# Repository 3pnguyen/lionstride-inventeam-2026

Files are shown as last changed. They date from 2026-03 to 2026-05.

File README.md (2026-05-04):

# lionstride-inventeam-2026

## Branch for the schematic files of the circuit and device

 <!-- - --> 

<!-- Badeges from https://gprm.itsvg.in and https://github.com/Ileriayo/markdown-badges  -->

<div align="center">
    <table>
        <tr>
            <td></td>
            <td></td>
        </tr>
    </table>
</div>

## Images

| Prototype | Finalized |
| :---: | :---: |
| [Prototype VD (17.1)](Prototype%20Schematics/Prototype%20Schematic%20(VD)/Schematic%20Versions/Schematic%20V17/v17.1%20-%203.19.26/) | [Logic Schematic (V3)](Finalized%20Schematics/Finalized%20Logic%20Schematic/Schematic%20Versions/Schematic%20V03/) |
| Prototype TIA | [Thermistor Schematic (V2)](Finalized%20Schematics/Finalized%20Thermistor%20Schematic/Schematic%20Versions/Schematic%20V02/) | 
| | [Pressure Schematic (V2.2)](Finalized%20Schematics/Finalized%20Pressure%20Schematic/Schematic%20Versions/Schematic%20V02/V2.2%20-%205.3.2026/) |

<!-- %20 is used as a space -->

## Purpose

This branch holds all of the KiCad files of our schematics and electrical designs. Our prototype schematic holds everything, and is the main design that has gone through the most change. As we transition from a prototype build to a finished product, parts of our prototype become "finalized." Finalized schematics seperate into their own folder with their own changelogs and PCB design. Even those schematics undergo some significant change indicated by their version number.

## Changelogs

| Prototype | Finalized |
| :---: | :---: |
| [Prototype VD](Prototype%20Schematics/Prototype%20Schematic%20(VD)/changelog.md) | [Logic Schematic](Finalized%20Schematics/Finalized%20Logic%20Schematic/changelog.md) |
| Prototype TIA | [Thermistor Schematic](Finalized%20Schematics/Finalized%20Thermistor%20Schematic/changelog.md) | 
| | [Pressure Schematic](Finalized%20Schematics/Finalized%20Pressure%20Schematic/changelog.md) |

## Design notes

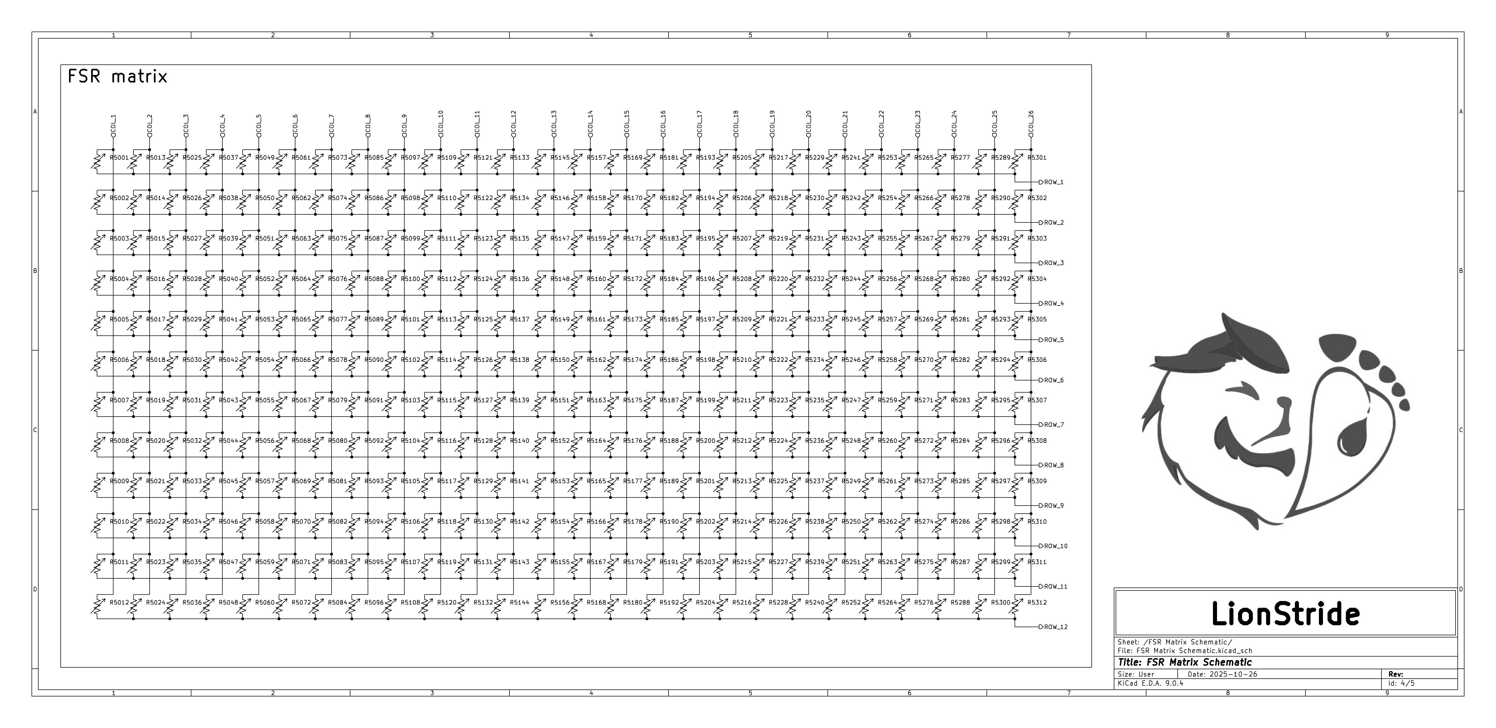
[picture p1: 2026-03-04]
Prototype Schematics/Prototype Schematic (VD)/Schematic Versions/Schematic V17/v17.1 - 3.19.26/FSR Matrix.png

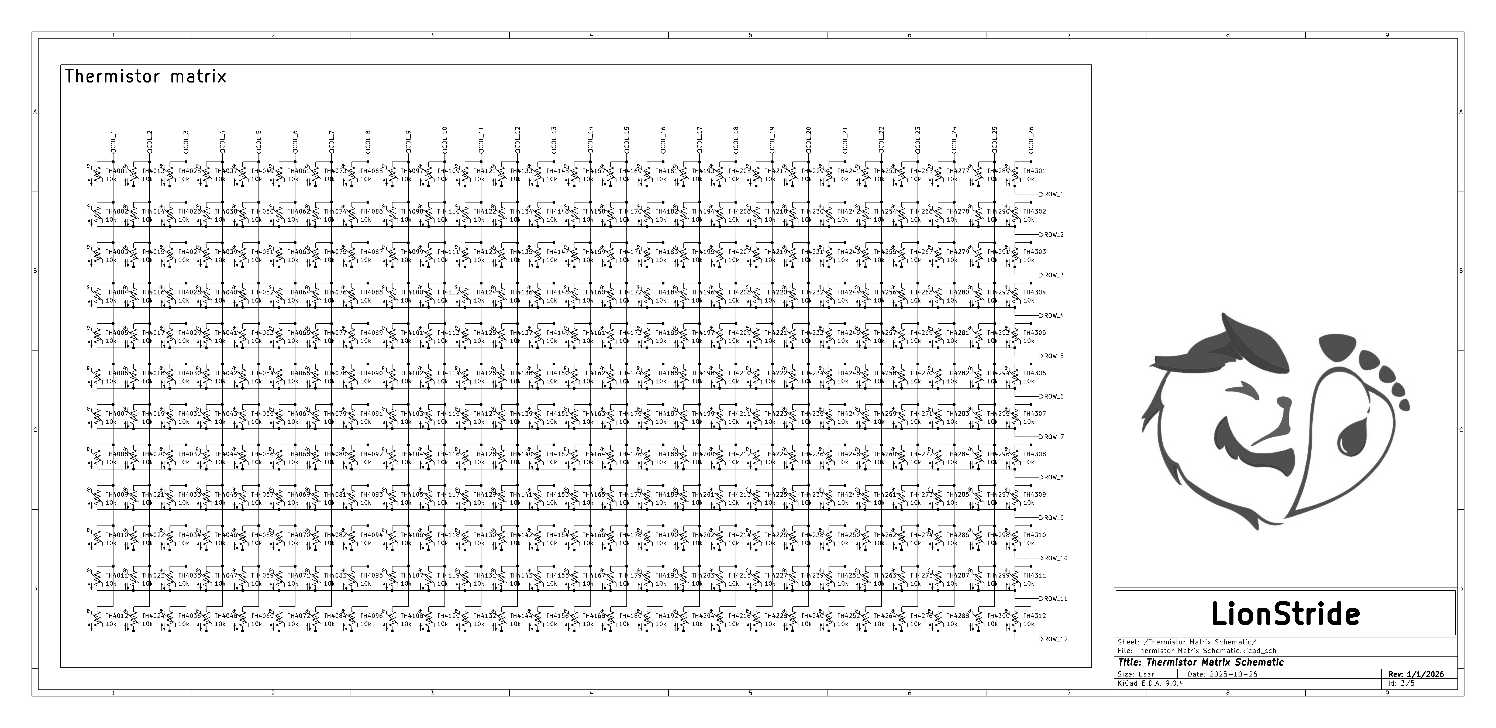
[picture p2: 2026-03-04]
Prototype Schematics/Prototype Schematic (VD)/Schematic Versions/Schematic V17/Thermistor Matrix.png

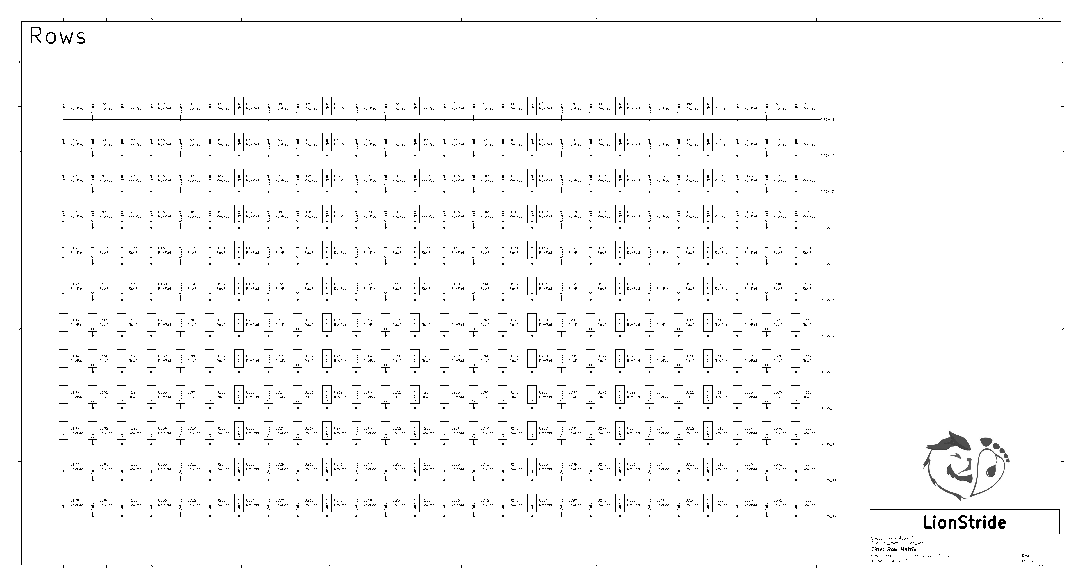
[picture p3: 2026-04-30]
Finalized Schematics/Finalized Pressure Schematic/Schematic Versions/Schematic V02/Rows Hierarchical Schematic.png

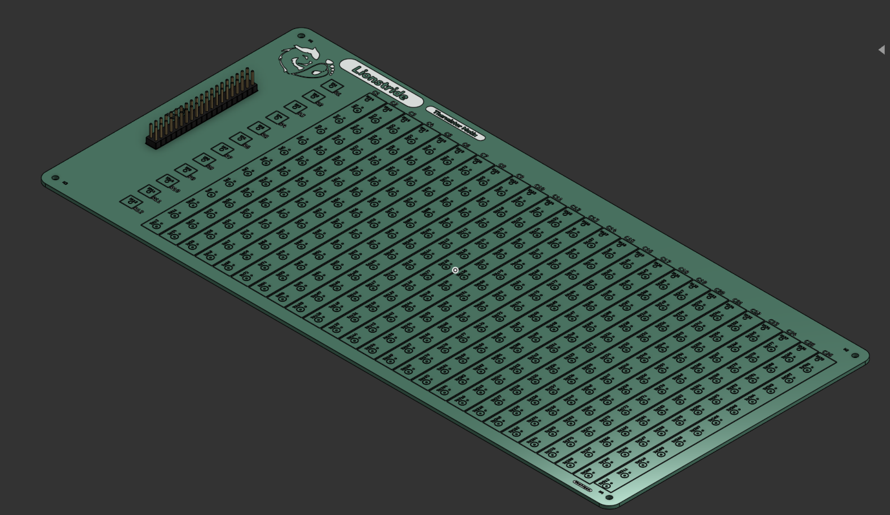
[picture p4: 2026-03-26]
Finalized Schematics/Finalized Thermistor Schematic/Schematic Versions/Schematic V02/Matrix Onshape.png

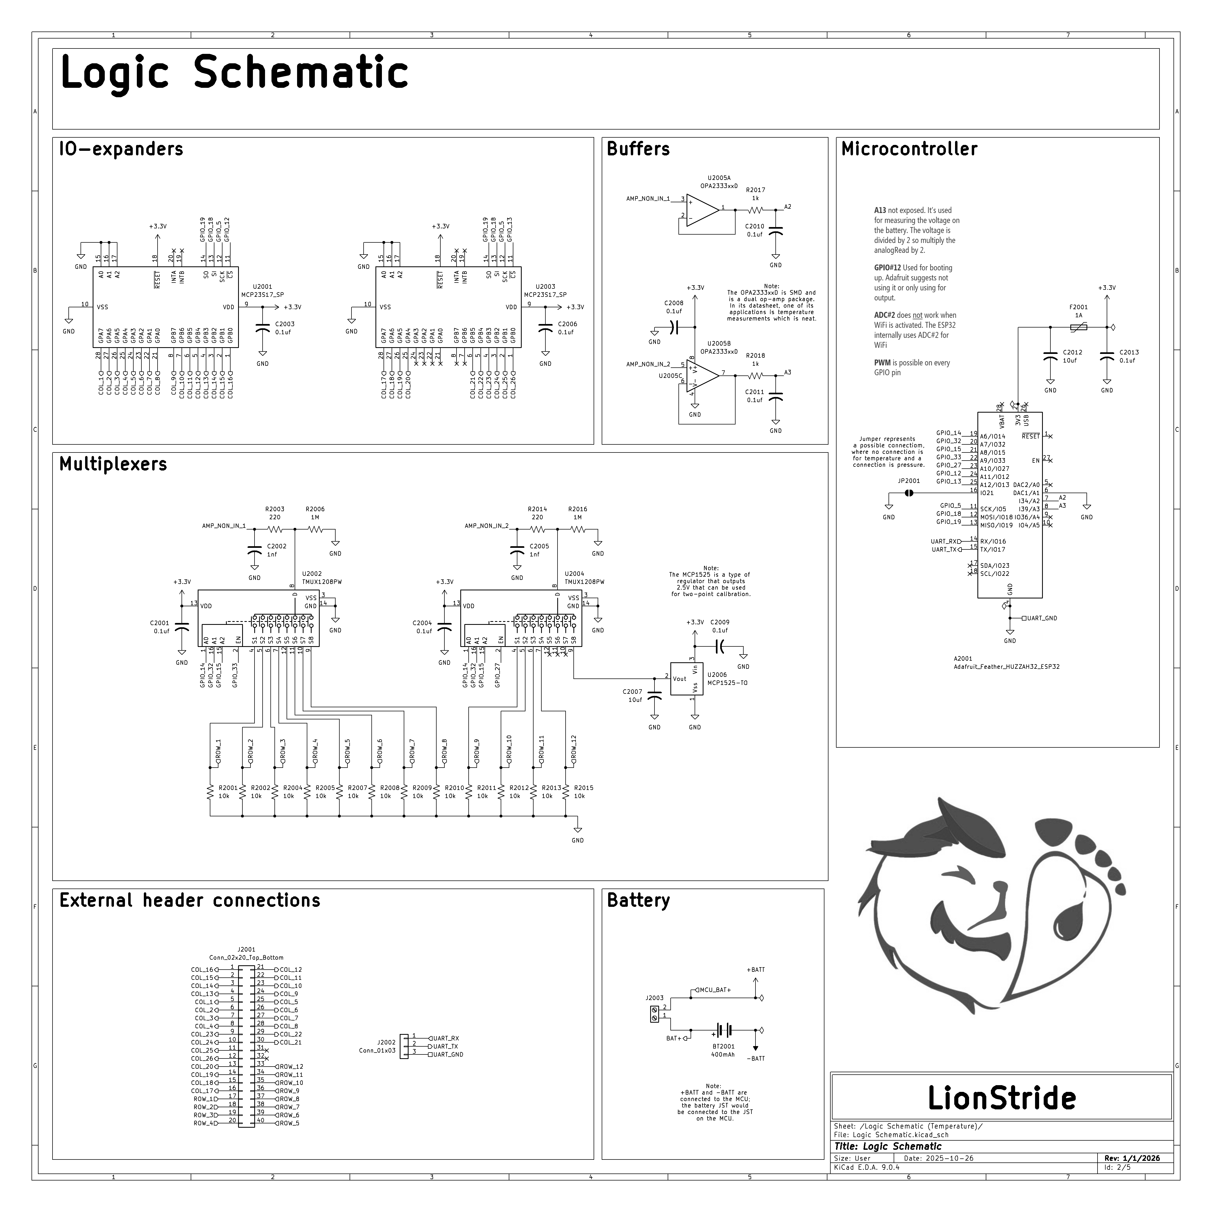
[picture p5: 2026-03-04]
Prototype Schematics/Prototype Schematic (VD)/Schematic Versions/Schematic V17/Logic Schematic.png

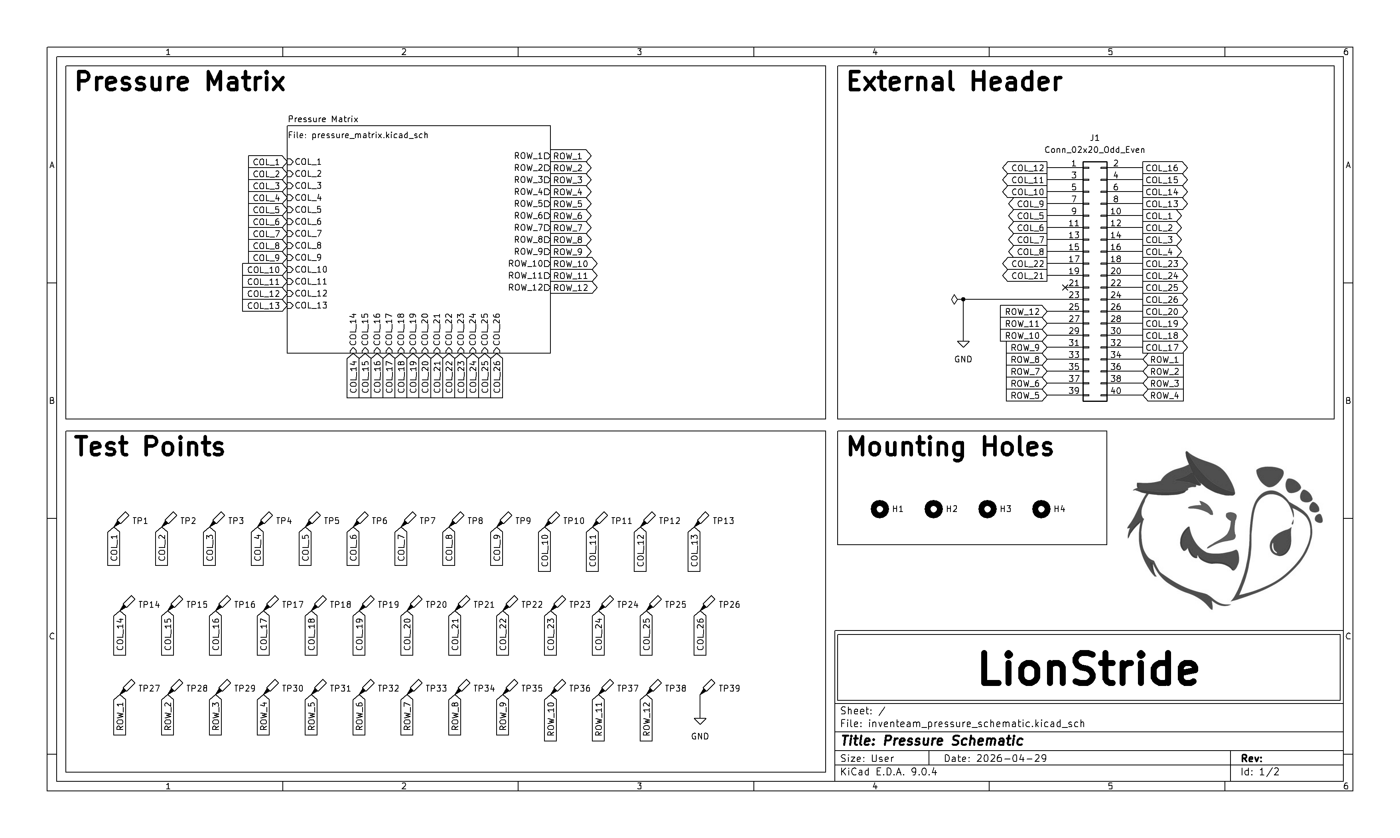
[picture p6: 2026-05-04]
Finalized Schematics/Finalized Pressure Schematic/Schematic Versions/Schematic V02/V2.2 - 5.3.2026/Pressure Schematic.png

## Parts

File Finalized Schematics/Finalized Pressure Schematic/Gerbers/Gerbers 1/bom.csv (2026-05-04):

Designator | Footprint | Quantity | Value | LCSC Part #
J1 | PinHeader_2x20_P2.54mm_Vertical | 1 | Conn_02x20_Odd_Even
TP1, TP10, TP11, TP12, TP13, TP14, TP15, TP16, TP17, TP18, TP19, TP2, TP20, TP21, TP22, TP23, TP24, TP25, TP26, TP27, TP28, TP29, TP3, TP30, TP31, TP32, TP33, TP34, TP35, TP36, TP37, TP38, TP39, TP4, TP5, TP6, TP7, TP8, TP9 | TestPoint_Pad_D2.5mm | 39 | TestPoint_Probe

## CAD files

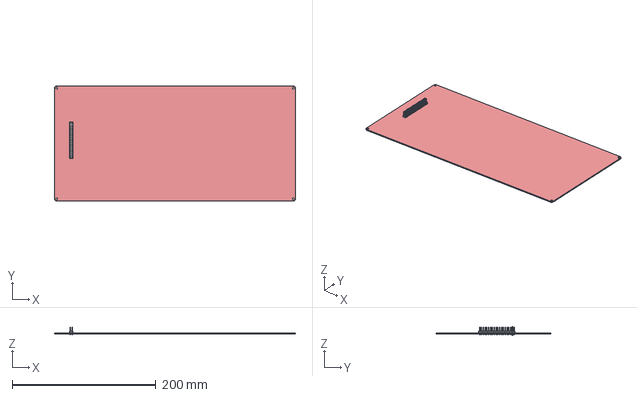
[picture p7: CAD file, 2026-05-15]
Finalized Schematics/Finalized Pressure Schematic/Gerbers/Gerbers 1/inventeam_pressure_schematic.step
335.0 x 160.0 x 11.5 mm
PinHeader_2x20_P2.54mm_Vertical
inventeam_pressure_schematic_PCB

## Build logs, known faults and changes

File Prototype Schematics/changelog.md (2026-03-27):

# Prototype design changelog:

(Version descriptions have been added since V16.1, so older version descriptions may be inaccurate.)

* V1 - 10.25.25: Original, early concept of the matrix design w/ the hardware to drive it
* V2 - 10.26.25: KiCad representation of V1
* V3 - 10.26.25: Concept for bigger matrix
* V4 - 10.26.25:  V2 refined with filtering and battery power
* V5 - 10.27.25: V4 but doubled matrix for two feet design
* V6 - 11.5.25: Revert back to one matrix and increase matrix size with more hardware
* V7 - 11.5.25: Revisions of V6 with better and more hardware
* V8 - 11.6.25: KiCad representation of V7
* V9 - 11.12.25: Separated V8 setup into hierarchical sheets for modular setup
* V10 - 11.14.25: Moved matrix into hierarchical sheet + more revisions
* V11 - 11.20.25: Refined hierarchical schematics more
* V12 - 11.27.25: More refinement w/ filtering on the ADCs
* V13 - 12.1.25: Added more decoupling and added more protection w/ polyfuses
	* V13.1 - 12.7.25: Added operational-amplifiers as voltage followers
	* V13.2 - 12.26.25: Added reference IC
* V14 - 1.1.26: Combine row and column hierarchical schematics together
	* V14.1 - 1.2.26: Switched row and column terminals to headers
	* V14.2 - 1.9.26: Combine row and column headers into one
	* V14.3 - 1.10.26: Removed external LED in favor of code
* V15 - 1.25.26: Added back the second matrix for pressure, created a logic schematic for pressure too
	* V15.1 - 2.13.26: Change decoupler on ref. IC output from 1uf to 10uf (no recording because I forgot)
	* V15.2 - 2.19.26: Added missing row 12 on the main header
* V16 - 2.22.26: Added RC filters and pull-down resistors between MUX drain pins and OP AMP non-inverting inputs
	* V16.1 - 3.2.26: Fixed reference designator conflicts and updated file names
* V17 - 3.3.26: Made universal version of logic schematic and moved reference IC to spare MUX pin
	* V17.1 - 3.19.26 - grounded one of the pins on the header

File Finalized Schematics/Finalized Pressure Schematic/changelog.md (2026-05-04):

# Finalized Pressure Schematic changelog:

* V1 - 4.11.26: Initialized first version of the pressure schematic 
* V2 - 4.29.26: Redesgined pressure schematic following changes of design
    * V2.1 - Modified V2 by adding test points and removing cell footprints in favor of one large one
    * V2.2 - Added GND test point, flipped the connections on the header

# Gerber files:
* Gerbers 1 (Schematic V2.2) - 5.3.2026: Created PCB design for schematic V2.2

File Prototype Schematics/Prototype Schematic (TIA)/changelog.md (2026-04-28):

# Prototype (TIA) design changelog:

* V0 - 4.27.26: Duplicated VD prototype (V17.1) to prepare for modifications on the newer prototype

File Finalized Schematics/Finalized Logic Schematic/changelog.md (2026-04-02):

# Finalized Logic Schematic chengelog:

* V1 - 3.18.26: Initialized and finished the initial PCB design schematic for the Logic schematic. (Two of the prototype Logic schematic + little extra)
	* V1.1 - 3.18.26: Optimize battery connections
	* V1.2 - 3.19.26: Add ground connections per header for thermistor matrix PCB
	* V1.3 - 3.27.26: Change header type on schematic, change 2A PPTC to 1A, added extra 0.1uf decoupler to USB C output, and finished assigning footprints
	* V1.4 - 3.28.26: Add 1x02 male header to make powering circuit more flexible + added missing decoupling for LM66100 ICs
* V2 - 3.31.2026: Made several optimizations and improvements including: Reording decouplers relative to IC(s), reording PPTC + TVS + decouplers relative to MCUs/sources, removing extra test points, moving the ADC RC filter next to the ADC for better filtering, and using hierarchal sheets again for the matrices logic
* V3 - 4.1.2026: Simplified schematic by removing USB C circuit, one ESP, and battery circuit. One ESP will be designated to drive two matrices

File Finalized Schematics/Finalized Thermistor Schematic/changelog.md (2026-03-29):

# Finalized Thermistor Matrix changelog:

* V1 - 3.20.26: Initialize schematic w/ additional header and mounting holes
* V2 - 3.25.26: Used hierarchal sheets to make PCB design easier (and made a PCB)

# Gerber files:

* Gerbers 1 (Schematic V2) - 3.25.26: Created PCB design for schematic V2
* Gerbers 2 (Schematic V2) - 3.29.26: Fixed problem where some of the PCB wasn't grounded w/ vias

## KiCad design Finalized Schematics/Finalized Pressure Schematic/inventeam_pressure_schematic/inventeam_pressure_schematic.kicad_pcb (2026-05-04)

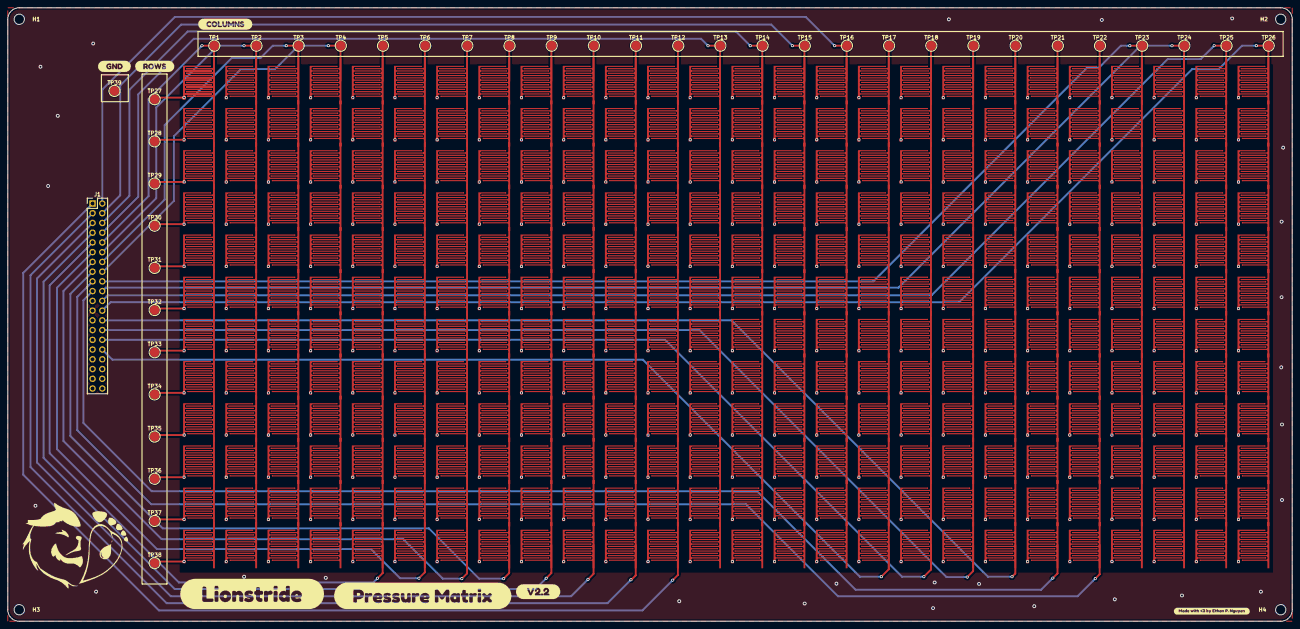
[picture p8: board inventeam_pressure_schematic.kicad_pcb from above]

Board: 4 copper layers, 335.0 x 160.0 mm, 51 parts (0 on the bottom side), 39 nets.

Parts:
H1, H2, H3, H4: MountingHole; MountingHole_2.7mm_M2.5
J1: Conn_02x20_Odd_Even; PinHeader_2x20_P2.54mm_Vertical
TP1, TP2, TP3, TP4, TP5, TP6, TP7, TP8, TP9, TP10, TP11, TP12, TP13, TP14, TP15, TP16, TP17, TP18, TP19, TP20, TP21, TP22, TP23, TP24, TP25, TP26, TP27, TP28, TP29, TP30, TP31, TP32, TP33, TP34, TP35, TP36, TP37, TP38, TP39: TestPoint_Probe; TestPoint_Pad_D2.5mm
kibuzzard-69F7F9B9: G***; kibuzzard-69F7F9B9
kibuzzard-69F7FA32: G***; kibuzzard-69F7FA32
kibuzzard-69F7FCC3: G***; kibuzzard-69F7FCC3
kibuzzard-69F7FCD4: G***; kibuzzard-69F7FCD4
kibuzzard-69F7FD79: G***; kibuzzard-69F7FD79
kibuzzard-69F8111F: G***; kibuzzard-69F8111F
kibuzzard-69F81189: G***; kibuzzard-69F81189

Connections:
COL_1: J1.10, TP1.1
COL_2: J1.12, TP2.1
COL_3: J1.14, TP3.1
COL_4: J1.16, TP4.1
COL_5: J1.9, TP5.1
COL_6: J1.11, TP6.1
COL_7: J1.13, TP7.1
COL_8: J1.15, TP8.1
COL_9: J1.7, TP9.1
COL_10: J1.5, TP10.1
COL_11: J1.3, TP11.1
COL_12: J1.1, TP12.1
COL_13: J1.8, TP13.1
COL_14: J1.6, TP14.1
COL_15: J1.4, TP15.1
COL_16: J1.2, TP16.1
COL_17: J1.32, TP17.1
COL_18: J1.30, TP18.1
COL_19: J1.28, TP19.1
COL_20: J1.26, TP20.1
COL_21: J1.19, TP21.1
COL_22: J1.17, TP22.1
COL_23: J1.18, TP23.1
COL_24: J1.20, TP24.1
COL_25: J1.22, TP25.1
COL_26: J1.24, TP26.1
GND: J1.23, TP39.1
ROW_1: J1.34, TP27.1
ROW_2: J1.36, TP28.1
ROW_3: J1.38, TP29.1
ROW_4: J1.40, TP30.1
ROW_5: J1.39, TP31.1
ROW_6: J1.37, TP32.1
ROW_7: J1.35, TP33.1
ROW_8: J1.33, TP34.1
ROW_9: J1.31, TP35.1
ROW_10: J1.29, TP36.1
ROW_11: J1.27, TP37.1
ROW_12: J1.25, TP38.1

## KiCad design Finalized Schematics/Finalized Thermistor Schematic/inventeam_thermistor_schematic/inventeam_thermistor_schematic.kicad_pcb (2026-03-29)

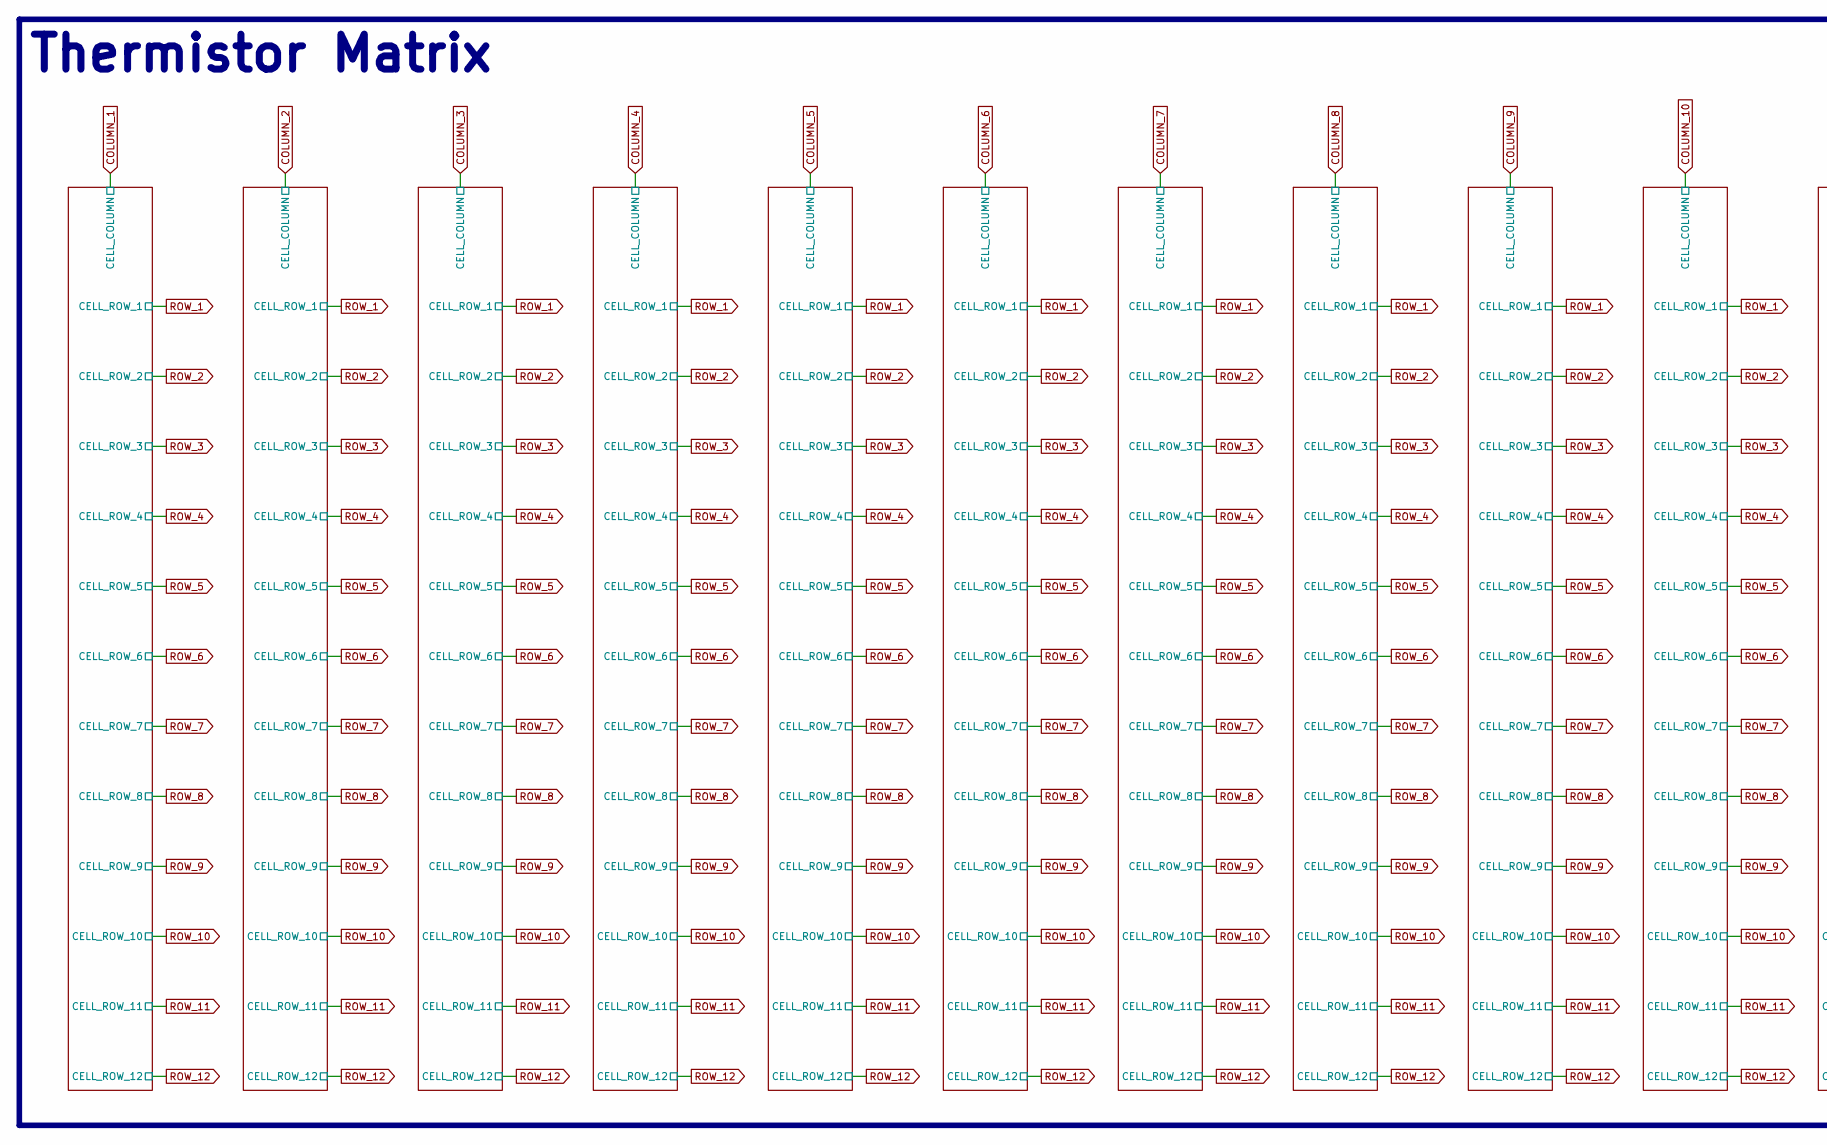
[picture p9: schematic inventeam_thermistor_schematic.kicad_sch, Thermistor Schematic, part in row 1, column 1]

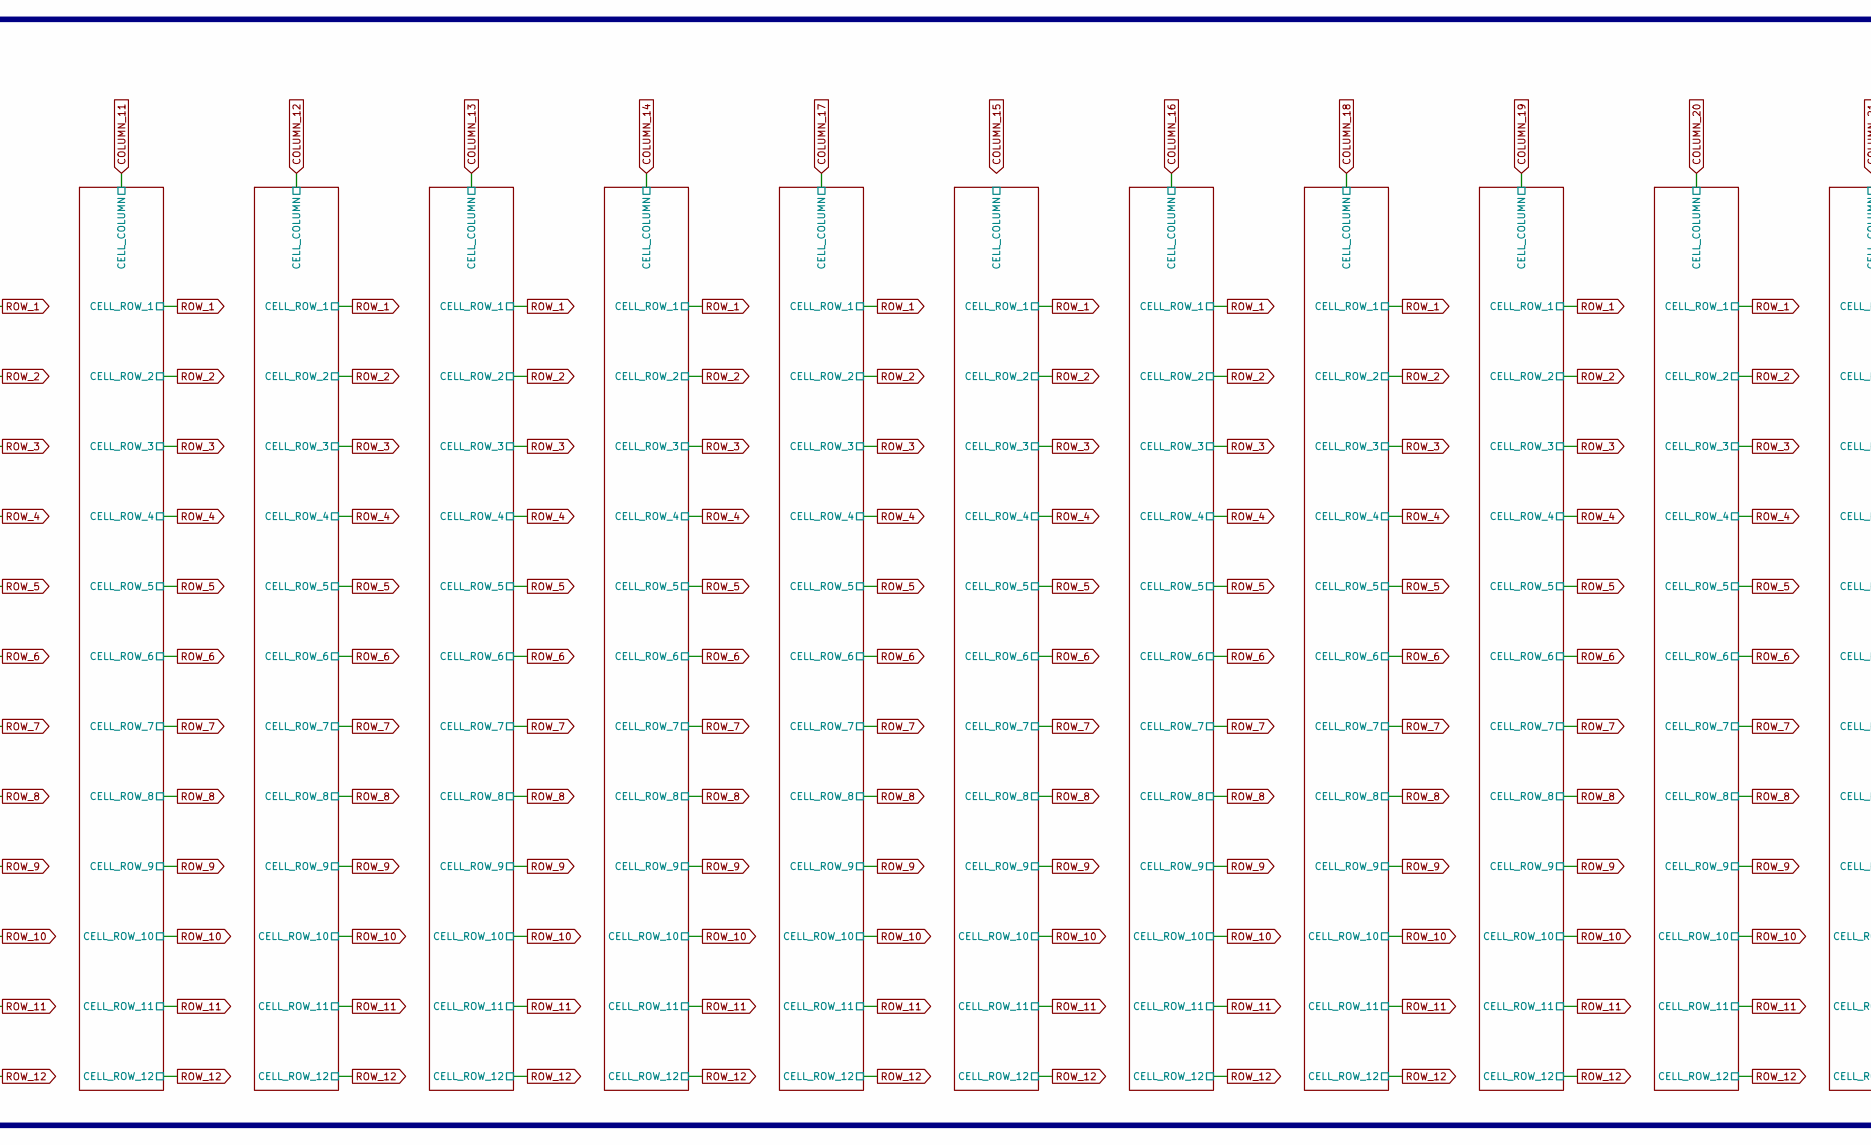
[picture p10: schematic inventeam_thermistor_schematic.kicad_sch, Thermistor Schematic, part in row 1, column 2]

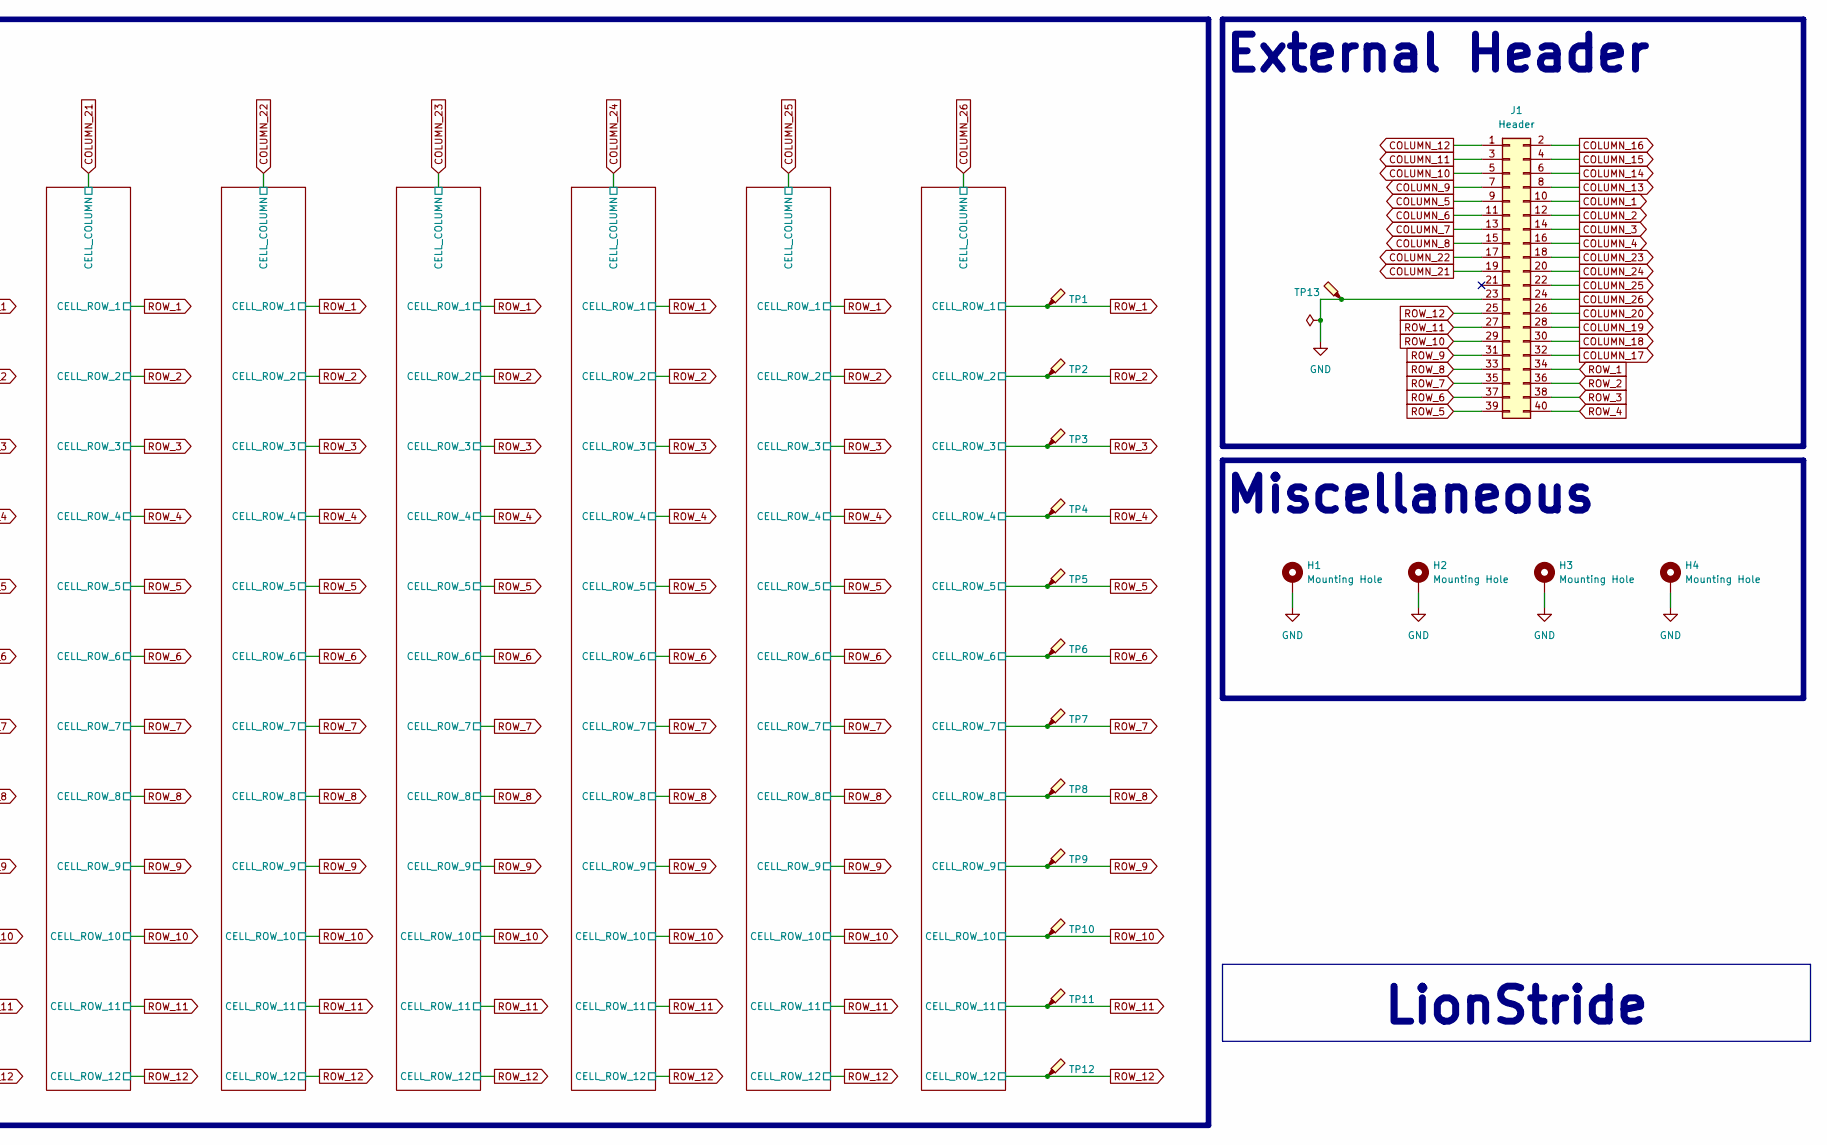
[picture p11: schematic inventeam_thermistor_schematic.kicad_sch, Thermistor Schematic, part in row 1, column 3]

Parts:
H1, H2, H3, H4: Mounting Hole; MountingHole_2.5mm_Pad
J1: Header; PinHeader_2x20_P2.54mm_Vertical
TP1, TP2, TP3, TP4, TP5, TP6, TP7, TP8, TP9, TP10, TP11, TP12, TP13: TestPoint_Probe; TestPoint_Pad_D1.0mm

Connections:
COLUMN_1: J1.10; also elsewhere on the board
COLUMN_2: J1.12; also elsewhere on the board
COLUMN_3: J1.14; also elsewhere on the board
COLUMN_4: J1.16; also elsewhere on the board
COLUMN_5: J1.9; also elsewhere on the board
COLUMN_6: J1.11; also elsewhere on the board
COLUMN_7: J1.13; also elsewhere on the board
COLUMN_8: J1.15; also elsewhere on the board
COLUMN_9: J1.7; also elsewhere on the board
COLUMN_10: J1.5; also elsewhere on the board
COLUMN_11: J1.3; also elsewhere on the board
COLUMN_12: J1.1; also elsewhere on the board
COLUMN_13: J1.8; also elsewhere on the board
COLUMN_14: J1.6; also elsewhere on the board
COLUMN_15: J1.4; also elsewhere on the board
COLUMN_16: J1.2; also elsewhere on the board
COLUMN_17: J1.32; also elsewhere on the board
COLUMN_18: J1.30; also elsewhere on the board
COLUMN_19: J1.28; also elsewhere on the board
COLUMN_20: J1.26; also elsewhere on the board
COLUMN_21: J1.19; also elsewhere on the board
COLUMN_22: J1.17; also elsewhere on the board
COLUMN_23: J1.18; also elsewhere on the board
COLUMN_24: J1.20; also elsewhere on the board
COLUMN_25: J1.22; also elsewhere on the board
COLUMN_26: J1.24; also elsewhere on the board
GND: H1.1, H2.1, H3.1, H4.1, J1.23, TP13.1
ROW_1: J1.34, TP1.1; also elsewhere on the board
ROW_2: J1.36, TP2.1; also elsewhere on the board
ROW_3: J1.38, TP3.1; also elsewhere on the board
ROW_4: J1.40, TP4.1; also elsewhere on the board
ROW_5: J1.39, TP5.1; also elsewhere on the board
ROW_6: J1.37, TP6.1; also elsewhere on the board
ROW_7: J1.35, TP7.1; also elsewhere on the board
ROW_8: J1.33, TP8.1; also elsewhere on the board
ROW_9: J1.31, TP9.1; also elsewhere on the board
ROW_10: J1.29, TP10.1; also elsewhere on the board
ROW_11: J1.27, TP11.1; also elsewhere on the board
ROW_12: J1.25, TP12.1; also elsewhere on the board

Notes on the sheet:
LionStride
Miscellaneous
External Header
Thermistor Matrix

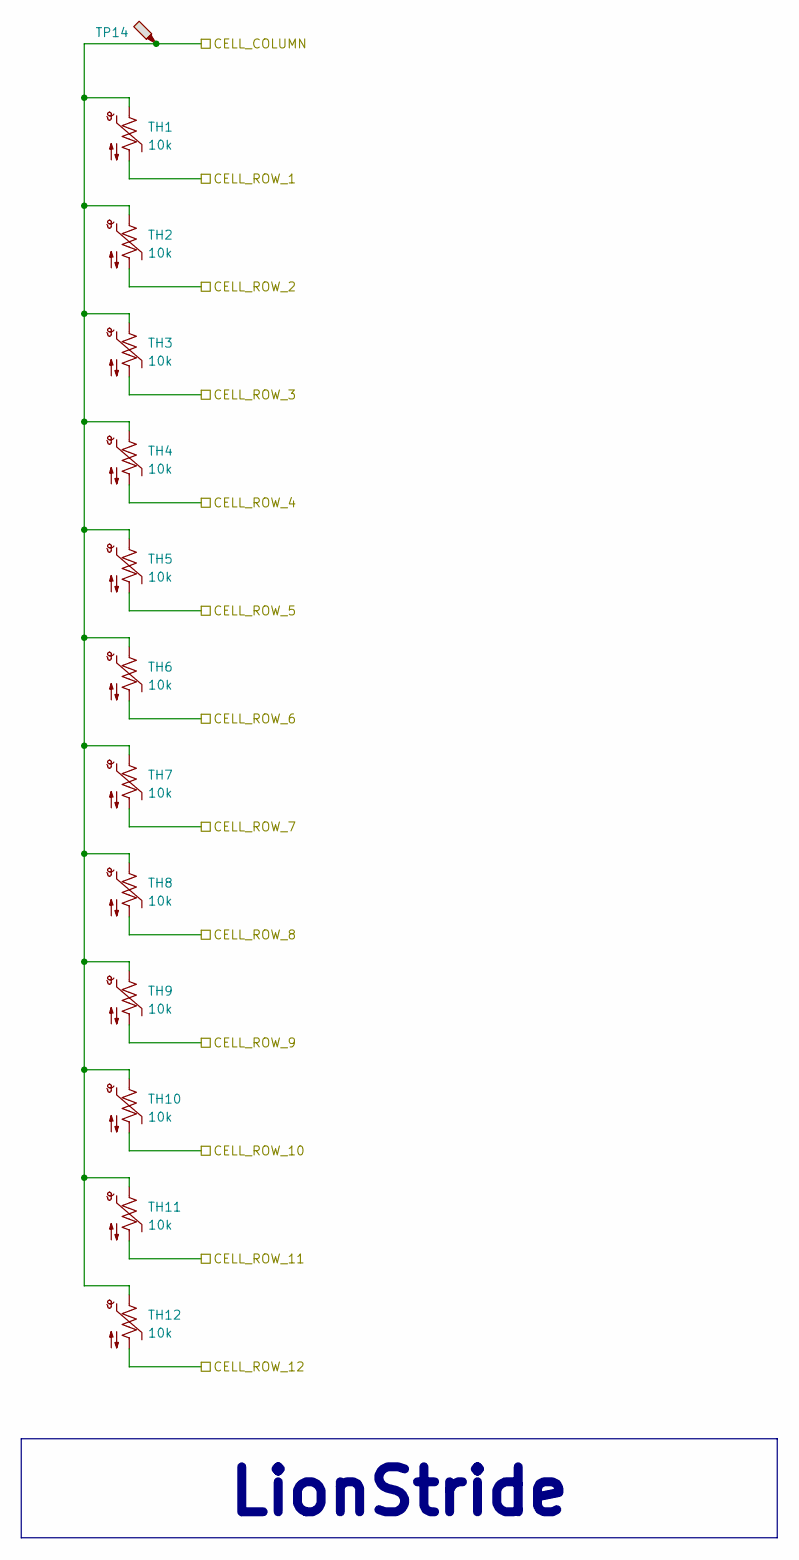
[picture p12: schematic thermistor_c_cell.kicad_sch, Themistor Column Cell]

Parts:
TH1, TH2, TH3, TH4, TH5, TH6, TH7, TH8, TH9, TH10, TH11, TH12: 10k; R_Axial_DIN0207_L6.3mm_D2.5mm_P2.54mm_Vertical
TP14: TestPoint_Probe; TestPoint_Pad_D1.0mm

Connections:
COLUMN_1: TH1.1, TH2.1, TH3.1, TH4.1, TH5.1, TH6.1, TH7.1, TH8.1, TH9.1, TH10.1, TH11.1, TH12.1, TP14.1; also elsewhere on the board
ROW_1: TH1.2; also elsewhere on the board
ROW_2: TH2.2; also elsewhere on the board
ROW_3: TH3.2; also elsewhere on the board
ROW_4: TH4.2; also elsewhere on the board
ROW_5: TH5.2; also elsewhere on the board
ROW_6: TH6.2; also elsewhere on the board
ROW_7: TH7.2; also elsewhere on the board
ROW_8: TH8.2; also elsewhere on the board
ROW_9: TH9.2; also elsewhere on the board
ROW_10: TH10.2; also elsewhere on the board
ROW_11: TH11.2; also elsewhere on the board
ROW_12: TH12.2; also elsewhere on the board

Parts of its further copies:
TH13, TH14, TH15, TH16, TH17, TH18, TH19, TH20, TH21, TH22, TH23, TH24, TH25, TH26, TH27, TH28, TH29, TH30, TH31, TH32, TH33, TH34, TH35, TH36, TH37, TH38, TH39, TH40, TH41, TH42, TH43, TH44, TH45, TH46, TH47, TH48, TH49, TH50, TH51, TH52, TH53, TH54, TH55, TH56, TH57, TH58, TH59, TH60, TH61, TH62, TH63, TH64, TH65, TH66, TH67, TH68, TH69, TH70, TH71, TH72, TH73, TH74, TH75, TH76, TH77, TH78, TH79, TH80, TH81, TH82, TH83, TH84, TH85, TH86, TH87, TH88, TH89, TH90, TH91, TH92, TH93, TH94, TH95, TH96, TH97, TH98, TH99, TH100, TH101, TH102, TH103, TH104, TH105, TH106, TH107, TH108, TH109, TH110, TH111, TH112, TH113, TH114, TH115, TH116, TH117, TH118, TH119, TH120, TH121, TH122, TH123, TH124, TH125, TH126, TH127, TH128, TH129, TH130, TH131, TH132, TH133, TH134, TH135, TH136, TH137, TH138, TH139, TH140, TH141, TH142, TH143, TH144, TH145, TH146, TH147, TH148, TH149, TH150, TH151, TH152, TH153, TH154, TH155, TH156, TH157, TH158, TH159, TH160, TH161, TH162, TH163, TH164, TH165, TH166, TH167, TH168, TH169, TH170, TH171, TH172, TH173, TH174, TH175, TH176, TH177, TH178, TH179, TH180, TH181, TH182, TH183, TH184, TH185, TH186, TH187, TH188, TH189, TH190, TH191, TH192, TH193, TH194, TH195, TH196, TH197, TH198, TH199, TH200, TH201, TH202, TH203, TH204, TH205, TH206, TH207, TH208, TH209, TH210, TH211, TH212, TH213, TH214, TH215, TH216, TH217, TH218, TH219, TH220, TH221, TH222, TH223, TH224, TH225, TH226, TH227, TH228, TH229, TH230, TH231, TH232, TH233, TH234, TH235, TH236, TH237, TH238, TH239, TH240, TH241, TH242, TH243, TH244, TH245, TH246, TH247, TH248, TH249, TH250, TH251, TH252, TH253, TH254, TH255, TH256, TH257, TH258, TH259, TH260, TH261, TH262, TH263, TH264, TH265, TH266, TH267, TH268, TH269, TH270, TH271, TH272, TH273, TH274, TH275, TH276, TH277, TH278, TH279, TH280, TH281, TH282, TH283, TH284, TH285, TH286, TH287, TH288, TH289, TH290, TH291, TH292, TH293, TH294, TH295, TH296, TH297, TH298, TH299, TH300, TH301, TH302, TH303, TH304, TH305, TH306, TH307, TH308, TH309, TH310, TH311, TH312: 10k; R_Axial_DIN0207_L6.3mm_D2.5mm_P2.54mm_Vertical
TP15, TP16, TP17, TP18, TP19, TP20, TP21, TP22, TP23, TP24, TP25, TP26, TP27, TP28, TP29, TP30, TP31, TP32, TP33, TP34, TP35, TP36, TP37, TP38, TP39: TestPoint_Probe; TestPoint_Pad_D1.0mm

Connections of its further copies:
COLUMN_2: TH13.1, TH14.1, TH15.1, TH16.1, TH17.1, TH18.1, TH19.1, TH20.1, TH21.1, TH22.1, TH23.1, TH24.1, TP15.1; also elsewhere on the board
COLUMN_3: TH25.1, TH26.1, TH27.1, TH28.1, TH29.1, TH30.1, TH31.1, TH32.1, TH33.1, TH34.1, TH35.1, TH36.1, TP16.1; also elsewhere on the board
COLUMN_4: TH37.1, TH38.1, TH39.1, TH40.1, TH41.1, TH42.1, TH43.1, TH44.1, TH45.1, TH46.1, TH47.1, TH48.1, TP17.1; also elsewhere on the board
COLUMN_5: TH49.1, TH50.1, TH51.1, TH52.1, TH53.1, TH54.1, TH55.1, TH56.1, TH57.1, TH58.1, TH59.1, TH60.1, TP18.1; also elsewhere on the board
COLUMN_6: TH61.1, TH62.1, TH63.1, TH64.1, TH65.1, TH66.1, TH67.1, TH68.1, TH69.1, TH70.1, TH71.1, TH72.1, TP19.1; also elsewhere on the board
COLUMN_7: TH73.1, TH74.1, TH75.1, TH76.1, TH77.1, TH78.1, TH79.1, TH80.1, TH81.1, TH82.1, TH83.1, TH84.1, TP20.1; also elsewhere on the board
COLUMN_8: TH85.1, TH86.1, TH87.1, TH88.1, TH89.1, TH90.1, TH91.1, TH92.1, TH93.1, TH94.1, TH95.1, TH96.1, TP21.1; also elsewhere on the board
COLUMN_9: TH97.1, TH98.1, TH99.1, TH100.1, TH101.1, TH102.1, TH103.1, TH104.1, TH105.1, TH106.1, TH107.1, TH108.1, TP22.1; also elsewhere on the board
COLUMN_10: TH109.1, TH110.1, TH111.1, TH112.1, TH113.1, TH114.1, TH115.1, TH116.1, TH117.1, TH118.1, TH119.1, TH120.1, TP23.1; also elsewhere on the board
COLUMN_11: TH121.1, TH122.1, TH123.1, TH124.1, TH125.1, TH126.1, TH127.1, TH128.1, TH129.1, TH130.1, TH131.1, TH132.1, TP24.1; also elsewhere on the board
COLUMN_12: TH133.1, TH134.1, TH135.1, TH136.1, TH137.1, TH138.1, TH139.1, TH140.1, TH141.1, TH142.1, TH143.1, TH144.1, TP25.1; also elsewhere on the board
COLUMN_13: TH145.1, TH146.1, TH147.1, TH148.1, TH149.1, TH150.1, TH151.1, TH152.1, TH153.1, TH154.1, TH155.1, TH156.1, TP26.1; also elsewhere on the board
COLUMN_14: TH157.1, TH158.1, TH159.1, TH160.1, TH161.1, TH162.1, TH163.1, TH164.1, TH165.1, TH166.1, TH167.1, TH168.1, TP27.1; also elsewhere on the board
COLUMN_15: TH169.1, TH170.1, TH171.1, TH172.1, TH173.1, TH174.1, TH175.1, TH176.1, TH177.1, TH178.1, TH179.1, TH180.1, TP28.1; also elsewhere on the board
COLUMN_16: TH181.1, TH182.1, TH183.1, TH184.1, TH185.1, TH186.1, TH187.1, TH188.1, TH189.1, TH190.1, TH191.1, TH192.1, TP29.1; also elsewhere on the board
COLUMN_17: TH193.1, TH194.1, TH195.1, TH196.1, TH197.1, TH198.1, TH199.1, TH200.1, TH201.1, TH202.1, TH203.1, TH204.1, TP30.1; also elsewhere on the board
COLUMN_18: TH205.1, TH206.1, TH207.1, TH208.1, TH209.1, TH210.1, TH211.1, TH212.1, TH213.1, TH214.1, TH215.1, TH216.1, TP31.1; also elsewhere on the board
COLUMN_19: TH217.1, TH218.1, TH219.1, TH220.1, TH221.1, TH222.1, TH223.1, TH224.1, TH225.1, TH226.1, TH227.1, TH228.1, TP32.1; also elsewhere on the board
COLUMN_20: TH229.1, TH230.1, TH231.1, TH232.1, TH233.1, TH234.1, TH235.1, TH236.1, TH237.1, TH238.1, TH239.1, TH240.1, TP33.1; also elsewhere on the board
COLUMN_21: TH241.1, TH242.1, TH243.1, TH244.1, TH245.1, TH246.1, TH247.1, TH248.1, TH249.1, TH250.1, TH251.1, TH252.1, TP34.1; also elsewhere on the board
COLUMN_22: TH253.1, TH254.1, TH255.1, TH256.1, TH257.1, TH258.1, TH259.1, TH260.1, TH261.1, TH262.1, TH263.1, TH264.1, TP35.1; also elsewhere on the board
COLUMN_23: TH265.1, TH266.1, TH267.1, TH268.1, TH269.1, TH270.1, TH271.1, TH272.1, TH273.1, TH274.1, TH275.1, TH276.1, TP36.1; also elsewhere on the board
COLUMN_24: TH277.1, TH278.1, TH279.1, TH280.1, TH281.1, TH282.1, TH283.1, TH284.1, TH285.1, TH286.1, TH287.1, TH288.1, TP37.1; also elsewhere on the board
COLUMN_25: TH289.1, TH290.1, TH291.1, TH292.1, TH293.1, TH294.1, TH295.1, TH296.1, TH297.1, TH298.1, TH299.1, TH300.1, TP38.1; also elsewhere on the board
COLUMN_26: TH301.1, TH302.1, TH303.1, TH304.1, TH305.1, TH306.1, TH307.1, TH308.1, TH309.1, TH310.1, TH311.1, TH312.1, TP39.1; also elsewhere on the board
ROW_1: TH13.2, TH25.2, TH37.2, TH49.2, TH61.2, TH73.2, TH85.2, TH97.2, TH109.2, TH121.2, TH133.2, TH145.2, TH157.2, TH169.2, TH181.2, TH193.2, TH205.2, TH217.2, TH229.2, TH241.2, TH253.2, TH265.2, TH277.2, TH289.2, TH301.2; also elsewhere on the board
ROW_2: TH14.2, TH26.2, TH38.2, TH50.2, TH62.2, TH74.2, TH86.2, TH98.2, TH110.2, TH122.2, TH134.2, TH146.2, TH158.2, TH170.2, TH182.2, TH194.2, TH206.2, TH218.2, TH230.2, TH242.2, TH254.2, TH266.2, TH278.2, TH290.2, TH302.2; also elsewhere on the board
ROW_3: TH15.2, TH27.2, TH39.2, TH51.2, TH63.2, TH75.2, TH87.2, TH99.2, TH111.2, TH123.2, TH135.2, TH147.2, TH159.2, TH171.2, TH183.2, TH195.2, TH207.2, TH219.2, TH231.2, TH243.2, TH255.2, TH267.2, TH279.2, TH291.2, TH303.2; also elsewhere on the board
ROW_4: TH16.2, TH28.2, TH40.2, TH52.2, TH64.2, TH76.2, TH88.2, TH100.2, TH112.2, TH124.2, TH136.2, TH148.2, TH160.2, TH172.2, TH184.2, TH196.2, TH208.2, TH220.2, TH232.2, TH244.2, TH256.2, TH268.2, TH280.2, TH292.2, TH304.2; also elsewhere on the board
ROW_5: TH17.2, TH29.2, TH41.2, TH53.2, TH65.2, TH77.2, TH89.2, TH101.2, TH113.2, TH125.2, TH137.2, TH149.2, TH161.2, TH173.2, TH185.2, TH197.2, TH209.2, TH221.2, TH233.2, TH245.2, TH257.2, TH269.2, TH281.2, TH293.2, TH305.2; also elsewhere on the board
ROW_6: TH18.2, TH30.2, TH42.2, TH54.2, TH66.2, TH78.2, TH90.2, TH102.2, TH114.2, TH126.2, TH138.2, TH150.2, TH162.2, TH174.2, TH186.2, TH198.2, TH210.2, TH222.2, TH234.2, TH246.2, TH258.2, TH270.2, TH282.2, TH294.2, TH306.2; also elsewhere on the board
ROW_7: TH19.2, TH31.2, TH43.2, TH55.2, TH67.2, TH79.2, TH91.2, TH103.2, TH115.2, TH127.2, TH139.2, TH151.2, TH163.2, TH175.2, TH187.2, TH199.2, TH211.2, TH223.2, TH235.2, TH247.2, TH259.2, TH271.2, TH283.2, TH295.2, TH307.2; also elsewhere on the board
ROW_8: TH20.2, TH32.2, TH44.2, TH56.2, TH68.2, TH80.2, TH92.2, TH104.2, TH116.2, TH128.2, TH140.2, TH152.2, TH164.2, TH176.2, TH188.2, TH200.2, TH212.2, TH224.2, TH236.2, TH248.2, TH260.2, TH272.2, TH284.2, TH296.2, TH308.2; also elsewhere on the board
ROW_9: TH21.2, TH33.2, TH45.2, TH57.2, TH69.2, TH81.2, TH93.2, TH105.2, TH117.2, TH129.2, TH141.2, TH153.2, TH165.2, TH177.2, TH189.2, TH201.2, TH213.2, TH225.2, TH237.2, TH249.2, TH261.2, TH273.2, TH285.2, TH297.2, TH309.2; also elsewhere on the board
ROW_10: TH22.2, TH34.2, TH46.2, TH58.2, TH70.2, TH82.2, TH94.2, TH106.2, TH118.2, TH130.2, TH142.2, TH154.2, TH166.2, TH178.2, TH190.2, TH202.2, TH214.2, TH226.2, TH238.2, TH250.2, TH262.2, TH274.2, TH286.2, TH298.2, TH310.2; also elsewhere on the board
ROW_11: TH23.2, TH35.2, TH47.2, TH59.2, TH71.2, TH83.2, TH95.2, TH107.2, TH119.2, TH131.2, TH143.2, TH155.2, TH167.2, TH179.2, TH191.2, TH203.2, TH215.2, TH227.2, TH239.2, TH251.2, TH263.2, TH275.2, TH287.2, TH299.2, TH311.2; also elsewhere on the board
ROW_12: TH24.2, TH36.2, TH48.2, TH60.2, TH72.2, TH84.2, TH96.2, TH108.2, TH120.2, TH132.2, TH144.2, TH156.2, TH168.2, TH180.2, TH192.2, TH204.2, TH216.2, TH228.2, TH240.2, TH252.2, TH264.2, TH276.2, TH288.2, TH300.2, TH312.2; also elsewhere on the board

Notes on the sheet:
LionStride

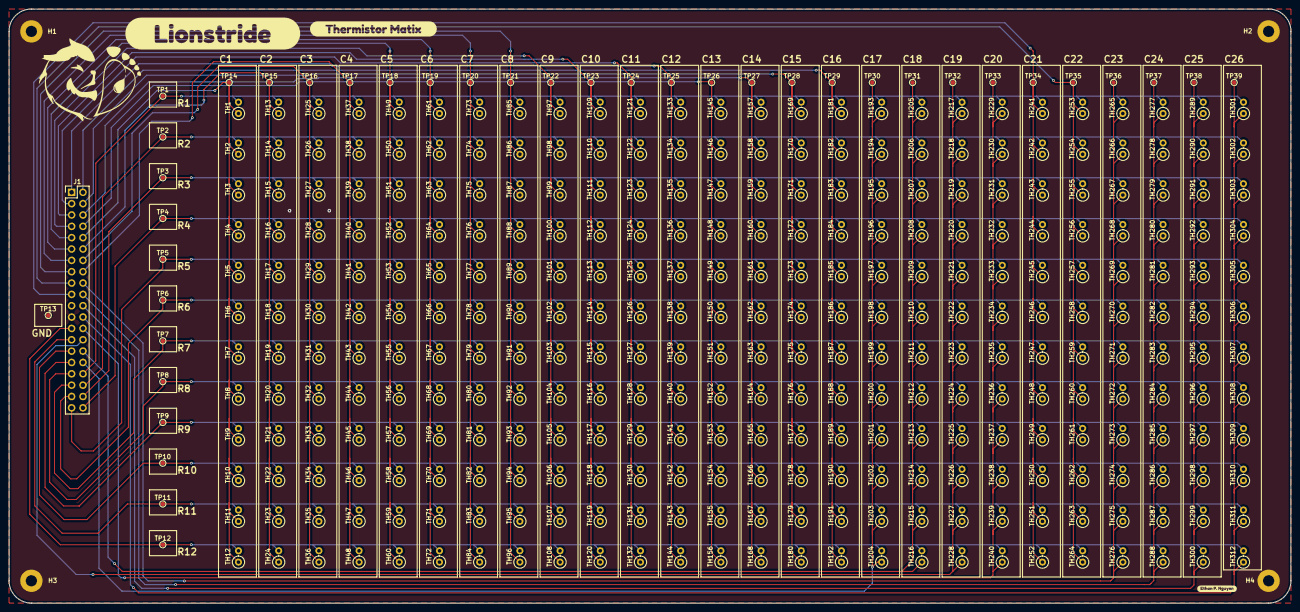
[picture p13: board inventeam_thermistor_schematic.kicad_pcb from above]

Board: 2 copper layers, 287.0 x 133.0 mm, 359 parts (0 on the bottom side), 39 nets.

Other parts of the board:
kibuzzard-69C4C7E1: G***; kibuzzard-69C4C7E1
kibuzzard-69C4C75F: G***; kibuzzard-69C4C75F
kibuzzard-69C4C905: G***; kibuzzard-69C4C905

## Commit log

2026-02-03 Add note for schematic finalization
    Added note about finalizing schematic.
2026-02-03 Add .gitignore for KiCad project files
2026-02-03 Add branch description for schematic files
    Added a branch description for schematic files.
2026-02-03 Update README with version timestamps
    Added version timestamps for schematic updates.
2026-02-07 Delete .gitignore
    KiCad templates already have one
2026-02-07 Added KiCad files
    [FSR Logic Schematic.kicad_sch, FSR Matrix Schematic.kicad_sch, Matrix_Columns.kicad_sch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]
2026-02-14 Change 1uf to 10uf
    [FSR Logic Schematic.kicad_sch, Matrix_Columns.kicad_sch, inventeam_proto_schematics.kicad_sch]
2026-02-20 Minor fix on row header
    [FSR Logic Schematic.kicad_sch, Matrix_Columns.kicad_sch]
2026-02-23 Schematic V16
    [FSR Logic Schematic.kicad_sch, Matrix_Columns.kicad_sch]
2026-03-03 v16 minor 1
    [FSR Logic Schematic.kicad_sch, FSR Matrix Schematic.kicad_sch, Matrix_Rows.kicad_sch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]
2026-03-03 Revise prototype changelog in README.md
    Updated prototype changelog with detailed version descriptions.
2026-03-03 Enhance prototype changelog with version details
    Updated version descriptions with detailed explanations for each version.
2026-03-04 Succesfully removed old logic schematics
    [FSR Logic Schematic.kicad_sch, Thermistor Logic Schematic.kicad_sch]
2026-03-04 Add KiCad badge to README
    Added KiCad badge to README for better visibility.
2026-03-13 Prepare PCB design stage
2026-03-13 Initialize PCB schematic
    [inventeam_final_schematic.kicad_pcb, inventeam_final_schematic.kicad_sch]
2026-03-17 Day 2 of PCB work
    [inventeam_final_schematic.kicad_sch]
2026-03-18 Finished USB C input
    [inventeam_final_schematic.kicad_sch]
2026-03-19 Logic PCB V1
    [inventeam_final_schematic.kicad_sch]
2026-03-19 added BOM for v1
2026-03-19 V1 minor 1
    [inventeam_final_schematic.kicad_sch]
2026-03-20 Prepare for finalized matrix
    [inventeam_final_schematic.kicad_pcb, inventeam_final_schematic.kicad_sch]
2026-03-20 Ground header pin for thermistor pcb
    [Logic Schematic.kicad_sch, inventeam_thermistor_schematic.kicad_pcb, inventeam_thermistor_schematic.kicad_sch]
2026-03-21 Thermistor schematic V1
    [inventeam_thermistor_schematic.kicad_sch]
2026-03-21 Work on PCB for thermistor
    [inventeam_thermistor_schematic.kicad_pcb]
2026-03-24 Work on V2 thermistor PCB
    [inventeam_thermistor_schematic.kicad_pcb, inventeam_thermistor_schematic.kicad_sch, thermistor_c_cell.kicad_sch]
2026-03-24 Finishead header connections
    [inventeam_thermistor_schematic.kicad_pcb]
2026-03-26 Thermistor finalized V2
    [inventeam_thermistor_schematic-B_Cu.gbr, inventeam_thermistor_schematic-B_Mask.gbr, inventeam_thermistor_schematic-B_Paste.gbr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]
2026-03-26 Update logs for thermistor V2
2026-03-27 Clarity for logic schematic + gerber zip
2026-03-27 Fix link for finalized logic schematic
2026-03-28 Logic schematic v1.3
    [inventeam_final_schematic.kicad_sch]
2026-03-28 Fix link for logic schematic v1.3
2026-03-28 Logic schematic v1.4
    [inventeam_final_schematic.kicad_pcb, inventeam_final_schematic.kicad_sch]
2026-03-29 Logic schematic V1.4+
    [inventeam_final_schematic.kicad_pcb, inventeam_final_schematic.kicad_sch]
2026-03-29 Removed extra 0.1uf capacitor
    [inventeam_final_schematic.kicad_pcb, inventeam_final_schematic.kicad_sch]
2026-03-29 Work on PCB for logic schematic
    [inventeam_final_schematic.kicad_pcb]
2026-03-29 Gerbers 2 for thermistor v2
    [inventeam_thermistor_schematic-B_Cu.gbr, inventeam_thermistor_schematic-B_Mask.gbr, inventeam_thermistor_schematic-B_Paste.gbr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]
2026-04-01 Logic schematic V2
    [inventeam_final_schematic.kicad_pcb, matrix_logic.kicad_sch]
2026-04-02 Logic schematic V3
    [inventeam_final_schematic.kicad_sch, matrix_logic.kicad_sch]
2026-04-10 Initialize finalized pressure schematics
    [pressure_column_schematic.kicad_pcb, pressure_column_schematic.kicad_sch, pressure_row_schematic.kicad_pcb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]
2026-04-11 initialized hierarchal sheets
    [column_cell.kicad_sch, pressure_column_schematic.kicad_sch, pressure_row_schematic.kicad_sch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]
2026-04-11 Worked on V1
    [pressure_row_schematic.kicad_sch, row_cell.kicad_sch]
2026-04-12 Work on V1
    [column_cell.kicad_sch, pressure_column_schematic.kicad_sch]
2026-04-12 Added missing revision date and title
    [pressure_row_schematic.kicad_sch, row_cell.kicad_sch]
2026-04-13 V1 of pressure schematic
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2026-04-28 Duped prototype VD schematic
    [FSR Matrix Schematic.kicad_sch, Logic Schematic.kicad_sch, Thermistor Matrix Schematic.kicad_sch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]
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2026-04-29 Removed finalized pressure v1 in favor of v2
    [column_cell.kicad_sch, pressure_column_schematic.kicad_pcb, pressure_column_schematic.kicad_sch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]
2026-04-30 Pressure Schematic V02
    [column_matrix.kicad_sch, inventeam_pressure_schematic.kicad_pcb, inventeam_pressure_schematic.kicad_sch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]
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2026-05-03 Pressure V2.1
    [inventeam_pressure_schematic.kicad_sch, pressure_matrix.kicad_sch, row_matrix.kicad_sch]
2026-05-03 Fixed header
    [inventeam_pressure_schematic.kicad_sch]
2026-05-04 Pressure V2.2
    [inventeam_pressure_schematic.kicad_pcb, inventeam_pressure_schematic.kicad_sch]
2026-05-04 Gerbers for pressure V2.2
    [bom.csv, designators.csv, inventeam_pressure_schematic.kicad_pcb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]
2026-05-15 Added file for CAD
    [inventeam_pressure_schematic.step]
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
